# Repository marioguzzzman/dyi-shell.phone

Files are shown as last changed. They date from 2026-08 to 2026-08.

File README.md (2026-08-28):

# 🐚 DIY Shell Phone

This repository is the open-source reference for the *DYI Shell Phone*, so anyone can build their own, part of **[She Tells, Sea Shells](https://shetells.stream/)**, an artistic research project, developing both an artwork, an installation of the Shetells artwork, and a toolkit. 

The project emerges from the simple, almost childlike gesture of holding a shell to the ear, hearing the ocean’s presence. This toolkit is conceived as a means for the waters of Esposende to exchange with their inhabitants, enabling acts of observation, remembrance, and speculation about the futures of water bodies. Through this, a playful voice is extended to the non-human presences and aquatic landscapes of the ecosystem.

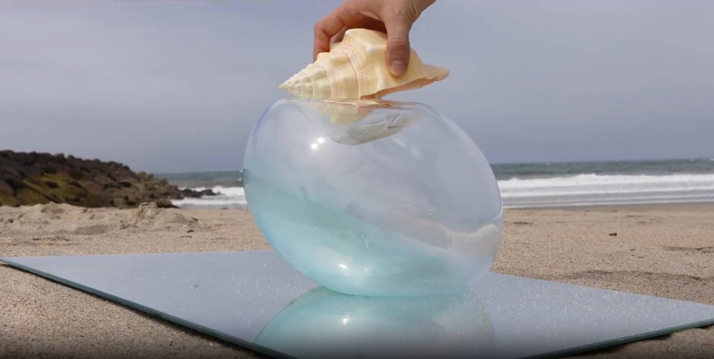
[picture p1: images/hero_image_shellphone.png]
The Shellphone


> **Status: work in progress.** The electronics (the custom audio board) are designed and documented here, and the 3D-printable shell is included. Step-by-step assembly guide with photos is being added.

---

## About the project

**English** - The Shellphone is a shell you can listen to. Inside a 3D-printed shell sits a Raspberry Pi Zero 2 W and a small custom audio board. When you hold the shell to your ear, it connects over WiFi to [shetells.stream](https://shetells.stream/) and plays its live **[stream](https://shetells.stream/stream.html)** - a flow of voices and memories that people have shared about water: the sea, rivers, drought, the things we are losing. It turns a familiar gesture - listening to a shell - into a way of listening to each other, and to the water. *(You can also explore the [Living Archive](https://shetells.stream/living-archive.html) to see the memories and the process behind the piece.)*

**Português** - O Shellphone é uma concha que se pode escutar. Dentro de uma concha impressa em 3D estão uma Raspberry Pi Zero 2 W e uma pequena placa de áudio feita à medida. Ao aproximar a concha do ouvido, liga-se por WiFi a [shetells.stream](https://shetells.stream/) e reproduz a sua **[transmissão ao vivo](https://shetells.stream/stream.html)** — um fluxo de vozes e memórias que as pessoas partilharam sobre a água: o mar, os rios, a seca, aquilo que estamos a perder. Transforma um gesto familiar - ouvir uma concha - numa forma de nos ouvirmos uns aos outros, e de ouvir a água. *(Também podes explorar o [Arquivo Vivo](https://shetells.stream/living-archive.html) para ver as memórias e o processo por detrás da peça.)*

---

## How it works

The Shellphone is three parts, hidden inside a shell:

1. **Raspberry Pi Zero 2 W** - a tiny WiFi computer. It connects to the internet and plays the live [stream](https://shetells.stream/stream.html) from [shetells.stream](https://shetells.stream/).
2. **Custom audio board** - a small PCB that plugs onto the Pi like a "HAT". It carries a **MAX98357A I2S amplifier** that turns the Pi's digital audio into a real signal, plus two LED "eyes". The board is shaped like a snail.
3. **Bone-conduction transducer** (8 Ω, 1 W) - instead of a normal speaker, a small transducer that makes whatever it touches vibrate. Mounted against the shell, it turns *the shell itself* into the speaker, so the sound seems to rise out of the shell in your hand.

Everything is powered over USB (5 V).

<p align="center">
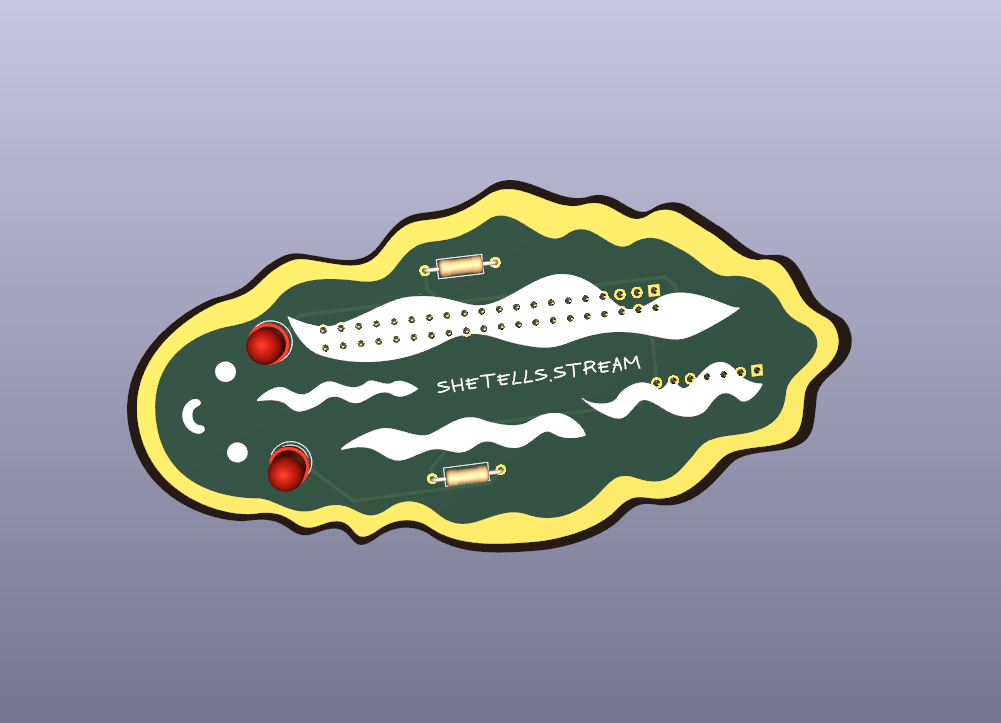
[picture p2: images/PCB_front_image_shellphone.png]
Audio board - front
  
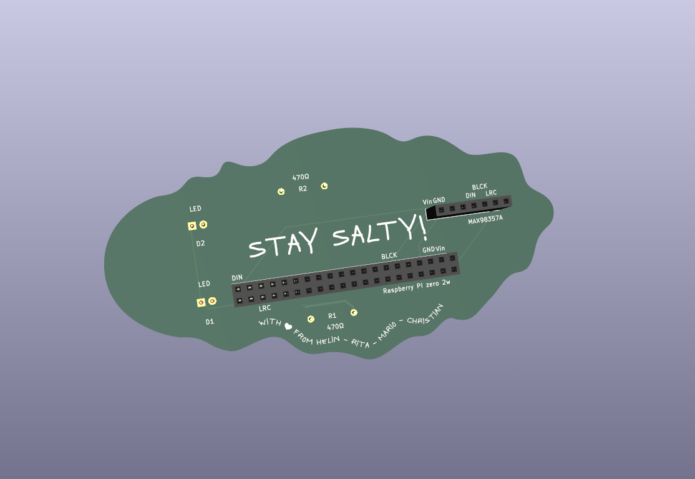
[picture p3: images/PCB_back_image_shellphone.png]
Audio board - back
  
</p>

The audio board connects to the Pi's audio pins like this:

| Amp signal | Raspberry Pi pin |
|---|---|
| Audio clock (BCLK) | GPIO18 (pin 12) |
| Word select (LRC) | GPIO19 (pin 35) |
| Audio data (DIN) | GPIO21 (pin 40) |
| Power (Vin) | 5V (pin 2) |
| Ground (GND) | GND (pin 6) |

*(Full board design: [`hardware/pcb/`](hardware/pcb/), a KiCad project.)*

---

## What's in this repo

| Folder / file | What's inside | Status |
|---|---|---|
| [`hardware/pcb/`](hardware/pcb/) | KiCad design files for the audio board | ✅ Designed |
| [`hardware/bom.md`](hardware/bom.md) | Bill of Materials - the full parts list | ✅ |
| [`enclosure/`](enclosure/) | 3D-printable shell (`.3mf`, `.obj`) | ✅ Included |
| [`images/`](images/) | Photos and board renders | ✅ |
| **Software** | Lives in a **separate repository** (not hosted here) | 🚧 Link coming |
| [`docs/`](docs/) | Assembly guide + build photos | 🚧 Coming |

---

## Build your own

1. **Get the parts** - see the [Bill of Materials](hardware/bom.md).
2. **Make the audio board** - open the KiCad project in [`hardware/pcb/`](hardware/pcb/), export the Gerber files, and send them to any PCB fab (e.g. JLCPCB, PCBWay).
3. **Print the shell** - print the model in [`enclosure/`](enclosure/).
4. **Set up the Raspberry Pi** - flash the SD card and install the streaming software from the [software repository](#software).
5. **Assemble** - solder the board, plug it onto the Pi, attach the bone-conduction transducer to the shell, and fit it all inside. 🚧 *Illustrated guide coming in `docs/`.*

---

## Software

The Raspberry Pi software (connecting to WiFi and playing the stream) lives in its own repository: 🚧 **[link coming soon]**

---

## Credits

Made by:

- **Helin Ulaş** - [helinulas.info](https://helinulas.info/)
- **Rita Eperjesi** - [rita.cloud](https://rita.cloud/)
- **Mario Guzman** - [mario-guzman.com](https://www.mario-guzman.com/)
- **Christian Kokott** - [kokott.art](https://kokott.art/)

Project realised within the framework of the [S+T+ARTS Aqua Motion artistic residency program](https://starts.eu/what-we-do/residences/startsaquamotion/), an initiative co-funded by the European Commission and hosted by [Rio Neiva](https://rioneiva.com/), Esposende, Portugal.

🌐 [shetells.stream](https://shetells.stream/) · 🔊 [Live stream](https://shetells.stream/stream.html) · 📚 [Living Archive](https://shetells.stream/living-archive.html)

<!-- 🚧 TODO: EU-funded acknowledgment line + logo. -->

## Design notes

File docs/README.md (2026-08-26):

# Docs

The step-by-step **assembly guide** and **build photos** will live here.

🚧 Coming soon — for now, the wiring is described in the main
[README](../README.md#how-it-works) and the parts are listed in the
[Bill of Materials](../hardware/bom.md).

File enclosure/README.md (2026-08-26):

# Enclosure — 3D-printable shell

The shell that houses the electronics. It's not just a case: the bone-conduction
transducer is mounted against it, so the shell itself vibrates and becomes the speaker.

## Files
- `hollowShell_full_new.3mf` — 3MF model (keeps print settings; open in a slicer like PrusaSlicer / Bambu Studio)
- `hollowShell_full.obj` — plain mesh (open in any 3D tool)

## Print settings
🚧 To add — recommended material, layer height, infill, supports, and any notes on
where the transducer and Raspberry Pi sit inside.

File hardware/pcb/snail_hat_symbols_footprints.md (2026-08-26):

# Sound Snail HAT — KiCad Symbols & Footprints Reference

A cheat-sheet for the custom snail PCB. The board is a **HAT**: it plugs down onto
the Raspberry Pi Zero 2 W. Stack from bottom to top: **Pi → (your components) → snail PCB**.

Because it's a HAT, the Pi interface on *your* board is a **female socket on the
bottom side**. You solder a normal male 2×20 header to the Pi; your board's socket
drops onto it.

---

## 1. Raspberry Pi Zero 2 W — 40-pin GPIO (the "row of 20 pins", ×2)

The Zero 2 W header is **2×20 = 40 pins**, 2.54 mm pitch (same layout as every Pi).

| | KiCad library:name |
|---|---|
| **Symbol** | `Connector:Raspberry_Pi_2_3` — 40-pin symbol with every GPIO already named (SDA, SCL, GPIO18, 5V, GND…). Much easier to wire than a blank header. |
| **Footprint** | `Connector_PinSocket_2.54mm:PinSocket_2x20_P2.54mm_Vertical` — **female** socket. |

Placement notes:
- Put the socket footprint on the **bottom copper layer** (place it, then press **F** to flip to back), so it faces the Pi.
- Keep the header in the official HAT position relative to the mounting holes if you want it to line up mechanically.

---

## 2. MAX98357A I2S amplifier

You're using the **breakout module** (the blue board in your drawing), so treat it as a
connector — you're not placing the bare chip.

| | KiCad library:name |
|---|---|
| **Symbol (control pins)** | `Connector_Generic:Conn_01x07` (7 pins: LRC, BCLK, DIN, GAIN, SD, GND, Vin) |
| **Footprint** | `Connector_PinHeader_2.54mm:PinHeader_1x07_P2.54mm_Vertical` (or `PinSocket_1x07…` if you want it removable) |
| **Speaker out symbol** | `Connector_Generic:Conn_01x02` (+ and −) |
| **Speaker out footprint** | `Connector_PinHeader_2.54mm:PinHeader_1x02_P2.54mm_Vertical`, or a screw terminal `TerminalBlock_Phoenix:TerminalBlock_Phoenix_MKDS-1,5-2_1x02_P5.00mm_Horizontal` |

*(If you ever switch to the bare IC instead of the breakout: symbol isn't in the default
libs — package is TQFN-16 3×3 mm, footprint `Package_DFN_QFN:TQFN-16-1EP_3x3mm_P0.5mm_EP1.8x1.8mm`.
Hard to hand-solder; stick with the breakout.)*

---

## 3. LEDs (the two snail eyes) — using 5 mm assortment

| | KiCad library:name |
|---|---|
| **Symbol** | `Device:LED` |
| **Footprint (THT 5 mm)** | `LED_THT:LED_D5.0mm` ← using this |

**Brightness note (assorted colors):** 470 Ω on a 3.3 V GPIO gives ~2.8 mA —
great for **red / yellow / orange / green**. **Blue and white** LEDs have a forward
voltage near 3.3 V, so they'll be dim. For bright blue/white eyes, drop to ~150–220 Ω
for those, or drive from 5 V through a small transistor.

---

## 4. Resistors — using 470 Ω

| | KiCad library:name |
|---|---|
| **Symbol** | `Device:R` (value 470) |
| **Footprint (THT axial)** | `Resistor_THT:R_Axial_DIN0207_L6.3mm_D2.5mm_P10.16mm_Horizontal` |
| **Footprint (SMD 0805)** | `Resistor_SMD:R_0805_2012Metric` |

One 470 Ω in series with each LED.

---

## 5. Optional but recommended

| Part | Symbol | Footprint |
|---|---|---|
| Mounting holes (Pi uses M2.5) | — | `MountingHole:MountingHole_2.7mm_M2.5` |
| Decoupling cap near amp (e.g. 100 nF / 10 µF) | `Device:C` | `Capacitor_SMD:C_0805_2012Metric` |

---

## 6. How to wire it (net connections)

**MAX98357A → Pi (I2S / PCM):**

| Amp pin | Pi signal | Physical pin |
|---|---|---|
| BCLK | GPIO18 (PCM_CLK) | 12 |
| LRC  | GPIO19 (PCM_FS)  | 35 |
| DIN  | GPIO21 (PCM_DOUT) | 40 |
| Vin  | 5V | 2 or 4 |
| GND  | GND | 6 (or any GND) |
| SD | leave unconnected (breakout defaults to ON) | — |
| GAIN | leave unconnected (= 9 dB gain) | — |

*(Only the 5 wires above — Vin, GND, DIN, BCLK, LRCLK — are needed. SD and GAIN
stay unconnected on the breakout.)*

**Speaker** → the amp's + and − output pads (4–8 Ω speaker).

**LEDs (snail eyes):** each LED anode → a free GPIO (e.g. GPIO17 = pin 11, GPIO27 = pin 13)
through its resistor; cathode → GND.

---

### Quick workflow in KiCad
1. Schematic editor → **Add Symbol (A)** → drop the symbols above.
2. Wire the nets per section 6, add net labels (5V, 3V3, GND, BCLK, LRC, DIN).
3. **Assign footprints** (or set them inline as above) → run **Annotate** + **ERC**.
4. **Update PCB from Schematic (F8)** → place parts, flip the Pi socket to the back layer.
5. Import your snail outline SVG as the **Edge.Cuts** / silk art, then route the red traces.

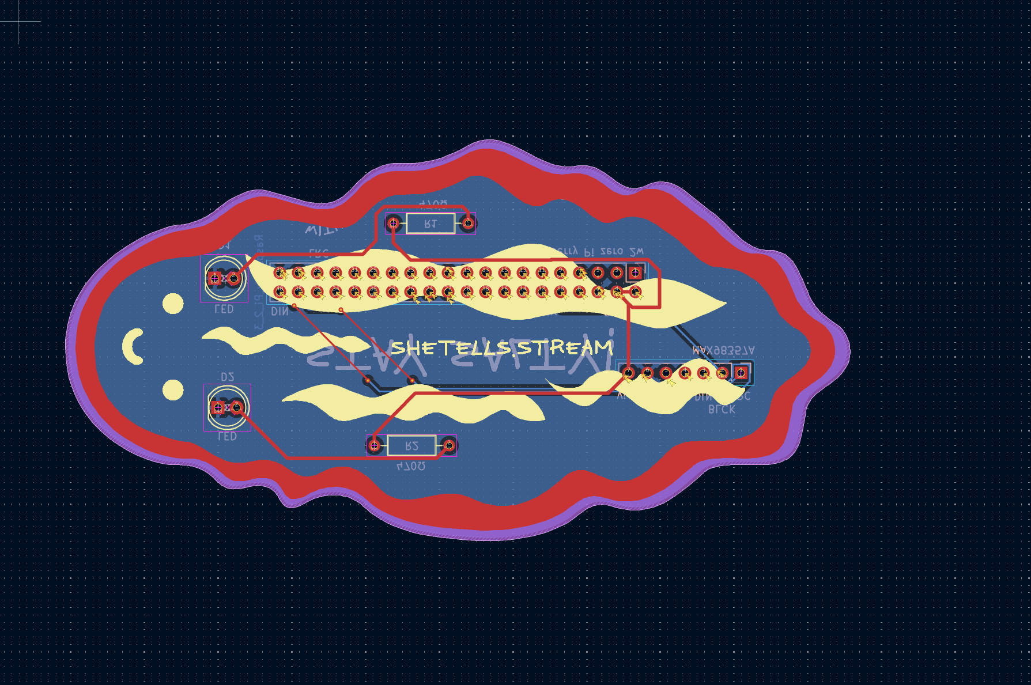
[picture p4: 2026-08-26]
images/PCB_shellphone.png

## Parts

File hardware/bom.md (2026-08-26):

# Bill of Materials (BOM)

Everything you need to build **one** Shellphone.

| # | Part | Qty | Notes / spec |
|---|---|-----|---|
| 1 | Raspberry Pi Zero 2 W | 1 | With WiFi (the "2 W"). Needs the 40-pin header soldered on. |
| 2 | microSD card | 1 | 8 GB or larger, for the Pi's software |
| 3 | Shellphone audio board (this project's PCB) | 1 | Export Gerbers from the KiCad project (`hardware/pcb/`) and order from a fab |
| 4 | MAX98357A I2S amplifier breakout | 1 | The blue audio amp module |
| 5 | Bone-conduction transducer, with wires | 1 | **8 Ω, 1 W** — vibrates the shell to make sound |
| 6 | 5 mm LEDs | 2 | The snail's "eyes" (any color) |
| 7 | Resistor, 470 Ω | 2 | One per LED |
| 8 | 2×20 male pin header, 2.54 mm | 1 | Soldered to the Raspberry Pi |
| 9 | 2×20 female socket, 2.54 mm | 1 | On the audio board, plugs onto the Pi |
| 10 | 1×07 female socket, 2.54 mm | 1 | On the audio board, for the MAX98357A |
| 11 | 3D-printed shell enclosure | 1 | Print from the files in `enclosure/` |
| 12 | USB power supply + cable | 1 | 5 V, micro-USB, to power the Pi |
| 13 | Hook-up wire | a little | To connect the transducer to the board |

### Notes
- Items 8–10 (the headers/sockets) are the connectors that let the boards plug together
  instead of being soldered permanently — easier to assemble and repair.

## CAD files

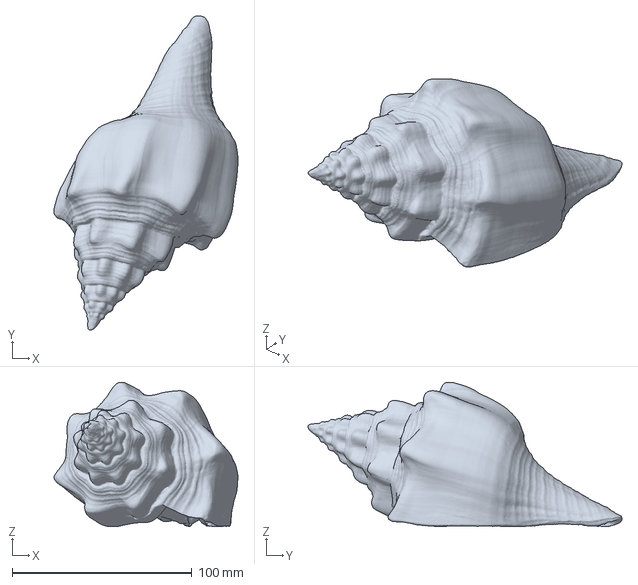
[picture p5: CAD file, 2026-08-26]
enclosure/hollowShell_full_new.3mf
102.4 x 174.8 x 80.4 mm

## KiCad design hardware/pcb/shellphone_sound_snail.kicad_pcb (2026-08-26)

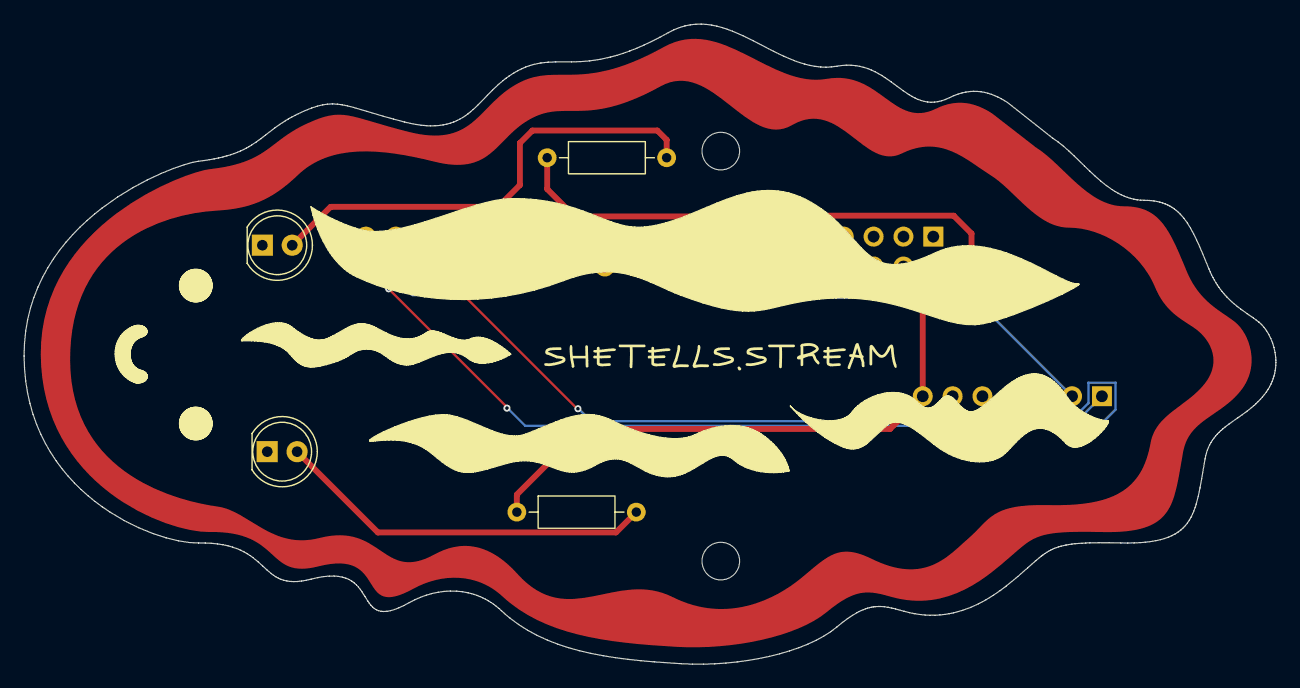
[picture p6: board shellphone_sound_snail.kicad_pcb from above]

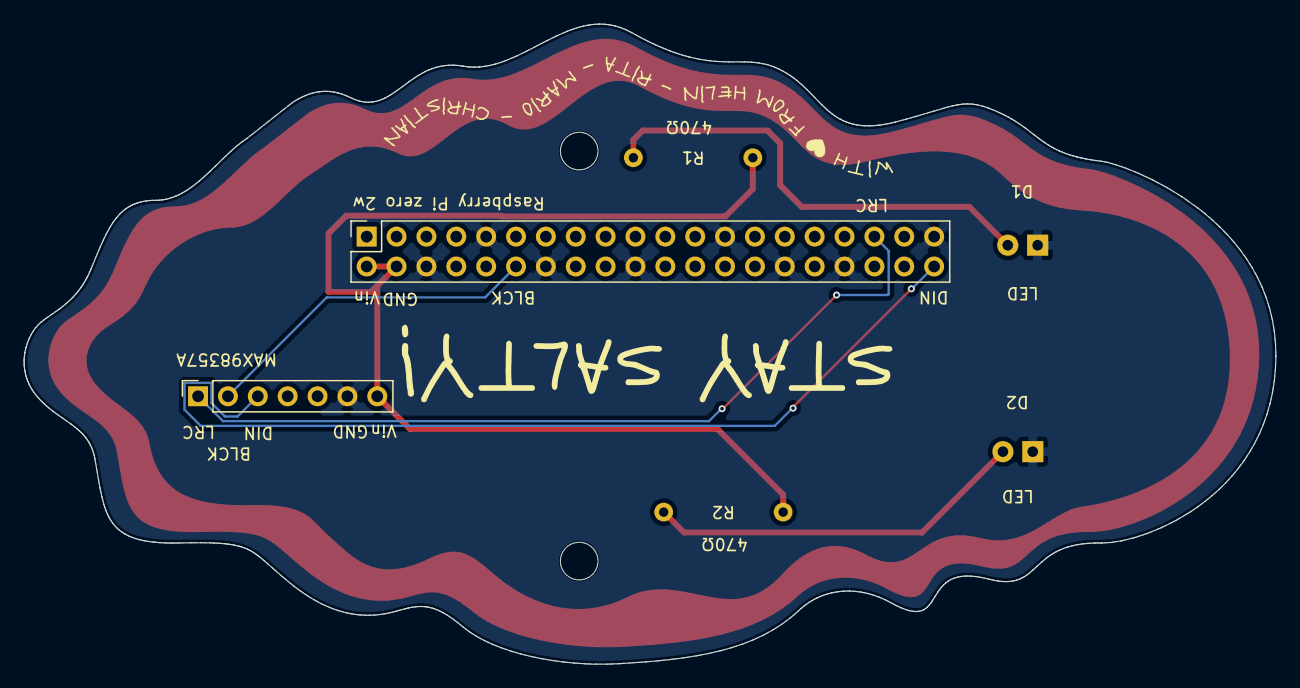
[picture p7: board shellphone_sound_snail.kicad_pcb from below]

Board: 2 copper layers, 106.5 x 54.4 mm, 8 parts (2 on the bottom side), 7 nets.

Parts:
D1, D2: LED; LED_D5.0mm
H1, H2: MountingHole; MountingHole_3.2mm_M3_DIN965
J1: Raspberry_Pi_2_3; PinSocket_2x20_P2.54mm_Vertical
J2: MAX98357A; PinSocket_1x07_P2.54mm_Vertical
R1, R2: 470Ω; R_Axial_DIN0207_L6.3mm_D2.5mm_P10.16mm_Horizontal

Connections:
/BCLK: J1.12 (GPIO18/PWM0), J2.2
/DIN: J1.40 (GPIO21/SCLK1), J2.3
/LRC: J1.35 (GPIO19/MISO1), J2.1
/Vin: J1.2 (5V), J1.4 (5V), J2.7, R1.1, R2.1
GND: D1.1 (K), D2.1 (K), J1.6 (GND), J1.9 (GND), J1.14 (GND), J1.20 (GND), J1.25 (GND), J1.30 (GND), J1.34 (GND), J1.39 (GND), J2.6
unnamed: D1.2 (A), R1.2
unnamed: D2.2 (A), R2.2
